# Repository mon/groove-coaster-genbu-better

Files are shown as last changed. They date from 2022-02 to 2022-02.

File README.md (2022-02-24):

# Genbu Groove Coaster alternative PCB + firmware

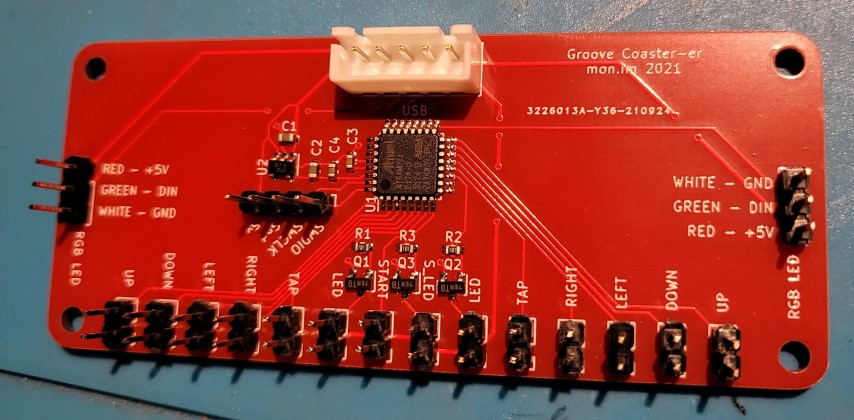
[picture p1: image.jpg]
PCB


Let's face it, the stock PCB is terrible. Totally impossible to modify, laggy,
boring.

This is one of many replacement PCBs for the Genbu con, using an ATSAMD21E17A-A.
It's a cheap ARM M0+ core from Microchip.
This particular chip is supported in the Arduino toolchain using MattairTech's
Arduino cores.

**The firmware does not support the Nintendo Switch** at the moment, but it
looks pretty simple to implement, so don't let that dissuade you if you're an
aspiring hacker.

Because my controller did not come with lights for the buttons (only for the
joystick), that's all the firmware does at the moment.

# Manufacture/soldering
I ordered a stencil + PCB from JLCPCB for ~$20 delivered (see the
groovin/gerbers folder, or use KiCad 6+ to generate them yourself), and use a $5
toaster oven I bought at a thrift shop to reflow solder the parts using Chip
Quik solder paste that I purchase from Digikey (along with all the other parts).
The switch connectors are all standard 2.54mm headers I cut into 2-pin units,
the resistors and capacitors I take from my 0603 resistor/capacitor book from
AliExpress.

The 3.3v regulator is not particularly exciting, as long as the pinout matches,
it should work fine.

**Ignore the picture** for the WS2812 headers, they should be female to properly
plug in to the Genbu LED connectors. I replaced the pins shortly after taking
the photo.

# Bootloader flashing
With my FT4232 breakout board, I used OpenOCD to flash the generic SAMD21
bootloader (included in this repository). I created a file called `post.cfg`
that reduced the adapter speed because I had some issues. Its entire contents
are `adapter speed 50`. I then ran `.\openocd.exe -f openocd.cfg -f
target/at91samdXX.cfg -f post.cfg`, connected via telnet, and executed `program
../sam_ba_Generic_x21E_SAMD21E17A.bin verify reset`.

# Firmware flashing
Once the bootloader is flashed, add the MattairTech board URL to your Arduino
install:  
`https://www.mattairtech.com/software/arduino/package_MattairTech_index.json`

Then select 
- Board: MattairTech MT-D21E Rev B (SAM D21/L21/C21, 32-pin)
- Microcontroller: SAMD21E17A
- Clock source: INTERNAL_USB_CALIBRATED_OSCILLATOR
- USB config: CDC_HID

Pin config is literally just digital pin 0-31 == PA0-PA31 -  SAMD is pretty nice!

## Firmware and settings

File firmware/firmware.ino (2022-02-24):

#include "Keyboard.h"
#include <Adafruit_NeoPixel.h>

#define _countof(x) (sizeof(x) / sizeof (x[0]))

#define LEDS_PER_BOOSTER 15
// full white, both boosters, under 500mA
#define LED_BRIGHTNESS 100

// they start at about the 2 o' clock position
struct {
  uint16_t start;
  uint16_t len;
} vectors[] = {
  {0, 4},
  {2, 4},
  {4, 3},
  {6, 4},
  {8, 3},
  {9, 4},
  {11, 4},
  {13, 3},
};

enum vector_indexes {
  RIGHT,
  DOWN_RIGHT,
  DOWN,
  DOWN_LEFT,
  LEFT,
  UP_LEFT,
  UP,
  UP_RIGHT,
};

enum booster {
  BOOST_LEFT = 0,
  BOOST_RIGHT = 1,
};

Adafruit_NeoPixel boost_left(LEDS_PER_BOOSTER, 17, NEO_GRB + NEO_KHZ800);
Adafruit_NeoPixel boost_right(LEDS_PER_BOOSTER, 16, NEO_GRB + NEO_KHZ800);

#define DEBOUNCE 50 // millis

struct {
  uint8_t pin;
  uint8_t key;
  uint8_t debounce;
} key_map[] = {
  // left booster
  {0, 'w'}, // up
  {1, 's'}, // down
  {2, 'a'}, // left
  {3, 'd'}, // right
  {4, ' '}, // click
  // start, use as coin
  {6, KEY_F3},
  // right booster
  {9, KEY_RIGHT_CTRL}, // click
  {10, KEY_RIGHT_ARROW}, // right
  {11, KEY_LEFT_ARROW}, // left
  {14, KEY_DOWN_ARROW}, // down
  {15, KEY_UP_ARROW}, // up
};

enum light_indexes {
  LEFT_UP = 0,
  LEFT_DOWN,
  LEFT_LEFT,
  LEFT_RIGHT,
  LEFT_TAP,
  START,
  RIGHT_TAP,
  RIGHT_RIGHT,
  RIGHT_LEFT,
  RIGHT_DOWN,
  RIGHT_UP
};

#define PRESSED(index) (key_map[index].debounce > 0)

// switch LEDs not done at the moment, maybe come back later

void setup() {
  boost_left.begin();
  boost_right.begin();
  boost_left.setBrightness(LED_BRIGHTNESS);
  boost_right.setBrightness(LED_BRIGHTNESS);

  //boost_left.fill(boost_left.Color(255,255,255));
  //boost_right.fill(boost_left.Color(255,255,255));
  //boost_left.show();
  //boost_right.show();
  
  for(size_t i = 0; i < _countof(key_map); i++) {
    pinMode(key_map[i].pin, INPUT_PULLUP);
  }


  Serial.begin(9600);
  Keyboard.begin();
}

void loop() {
  static unsigned long last_millis;
  static unsigned long last_led;

  unsigned long new_millis = millis();
  unsigned long ticks = new_millis - last_millis;
  last_millis = new_millis;

  if((new_millis - last_led) > 16) {
    last_led = new_millis;
    #define SPEED_DIVISOR 80
    uint32_t left_base = Wheel(new_millis / SPEED_DIVISOR);
    uint32_t right_base = Wheel((new_millis / SPEED_DIVISOR) + 128);
    uint32_t left_invert = left_base ^ 0xFFFFFF;
    uint32_t right_invert = right_base ^ 0xFFFFFF;

    boost_left.fill(left_base);
    boost_right.fill(right_base);

    if(PRESSED(LEFT_TAP)) {
      boost_left.fill(0xFFFFFF);
    }
    if(PRESSED(RIGHT_TAP)) {
      boost_right.fill(0xFFFFFF);
    }

    // this is incredibly shit
    if(PRESSED(LEFT_UP)) {
      if(PRESSED(LEFT_LEFT)) {
        draw_vector(UP_LEFT, BOOST_LEFT, left_invert);
      } else if(PRESSED(LEFT_RIGHT)) {
        draw_vector(UP_RIGHT, BOOST_LEFT, left_invert);
      } else {
        draw_vector(UP, BOOST_LEFT, left_invert);
      }
    } else if(PRESSED(LEFT_DOWN)) {
      if(PRESSED(LEFT_LEFT)) {
        draw_vector(DOWN_LEFT, BOOST_LEFT, left_invert);
      } else if(PRESSED(LEFT_RIGHT)) {
        draw_vector(DOWN_RIGHT, BOOST_LEFT, left_invert);
      } else {
        draw_vector(DOWN, BOOST_LEFT, left_invert);
      }
    } else if(PRESSED(LEFT_RIGHT)) {
      draw_vector(RIGHT, BOOST_LEFT, left_invert);
    } else if(PRESSED(LEFT_LEFT)) {
      draw_vector(LEFT, BOOST_LEFT, left_invert);
    }

    if(PRESSED(RIGHT_UP)) {
      if(PRESSED(RIGHT_LEFT)) {
        draw_vector(UP_LEFT, BOOST_RIGHT, right_invert);
      } else if(PRESSED(RIGHT_RIGHT)) {
        draw_vector(UP_RIGHT, BOOST_RIGHT, right_invert);
      } else {
        draw_vector(UP, BOOST_RIGHT, right_invert);
      }
    } else if(PRESSED(RIGHT_DOWN)) {
      if(PRESSED(RIGHT_LEFT)) {
        draw_vector(DOWN_LEFT, BOOST_RIGHT, right_invert);
      } else if(PRESSED(RIGHT_RIGHT)) {
        draw_vector(DOWN_RIGHT, BOOST_RIGHT, right_invert);
      } else {
        draw_vector(DOWN, BOOST_RIGHT, right_invert);
      }
    } else if(PRESSED(RIGHT_RIGHT)) {
      draw_vector(RIGHT, BOOST_RIGHT, right_invert);
    } else if(PRESSED(RIGHT_LEFT)) {
      draw_vector(LEFT, BOOST_RIGHT, right_invert);
    }

    //draw_vector(LEFT, BOOST_LEFT, left_invert);
    //draw_vector(DOWN, BOOST_RIGHT, right_invert);
    
    boost_left.show();
    boost_right.show();
  }
  
  for(size_t i = 0; i < _countof(key_map); i++) {
    if(!digitalRead(key_map[i].pin)) {
      key_map[i].debounce = DEBOUNCE;
      Keyboard.press(key_map[i].key);
      //Serial.print(i);
      //Serial.print(' ');
    } else {
      if(key_map[i].debounce > 0) {
        if(ticks > key_map[i].debounce) {
          key_map[i].debounce = 0;
        } else {
          key_map[i].debounce -= ticks;
        }
      } else {
        Keyboard.release(key_map[i].key);
      }
    }
  }
  //Serial.println(' ');

//  boost_left.fill(boost_left.Color(255,0,0));
//  boost_right.fill(boost_left.Color(255,0,0));
//  boost_left.show();
//  boost_right.show();
//  delay(500);
//  boost_left.fill(boost_left.Color(0,255,0));
//  boost_right.fill(boost_left.Color(0,255,0));
//  boost_left.show();
//  boost_right.show();
//  delay(500);
//  boost_left.fill(boost_left.Color(0,0,255));
//  boost_right.fill(boost_left.Color(0,0,255));
//  boost_left.show();
//  boost_right.show();
//  delay(500);
}

void draw_vector(enum vector_indexes dir, enum booster side, uint32_t colour) {
  uint16_t start = vectors[dir].start;
  uint16_t len = vectors[dir].len;
  for(uint16_t i = 0; i < len; i++) {
    uint16_t ind = (start + i) % LEDS_PER_BOOSTER;
    if(side == BOOST_LEFT) {
      boost_left.setPixelColor(ind, colour);
    } else {
      boost_right.setPixelColor(ind, colour);
    }
  }
}

// Input a value 0 to 255 to get a color value.
// The colours are a transition r - g - b - back to r.
uint32_t Wheel(byte WheelPos) {
  WheelPos = 255 - WheelPos;
  if(WheelPos < 85) {
    return boost_left.Color(255 - WheelPos * 3, 0, WheelPos * 3);
  }
  if(WheelPos < 170) {
    WheelPos -= 85;
    return boost_left.Color(0, WheelPos * 3, 255 - WheelPos * 3);
  }
  WheelPos -= 170;
  return boost_left.Color(WheelPos * 3, 255 - WheelPos * 3, 0);
}
